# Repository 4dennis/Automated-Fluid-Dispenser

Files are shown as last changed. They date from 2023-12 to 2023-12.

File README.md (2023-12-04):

# Automated-Fluid-Dispenser
Automated Fluid Dispenser code for a rotating rack that holds 5 test tubes and dispenses software-specified amounts of powder and liquid without user input. Includes emergency stop button. Uses an Arduino, limit switch, 2x push buttons, fluid pump, continuous servo, and a DC motor\
**For Solidworks files:** \
  Use Goat.forEdit4 assembly file\
  NoPrint indicates a part that is not for 3D or acrylic but is included in the build\
  AC indicates acrylic\
  3D indicates 3D printing\
  Nx where x stands for the number of pieces to produce\
\
-project created for APSC 101 with team members: Simon W., Lydia H., Cady K., Brady B.

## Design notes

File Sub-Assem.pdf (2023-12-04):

Automated Fluid Dispenser

29/10/23

| i

## Table of Contents

## 1. Exploded Views

Below is an exploded view of the entire assembly and each subassembly

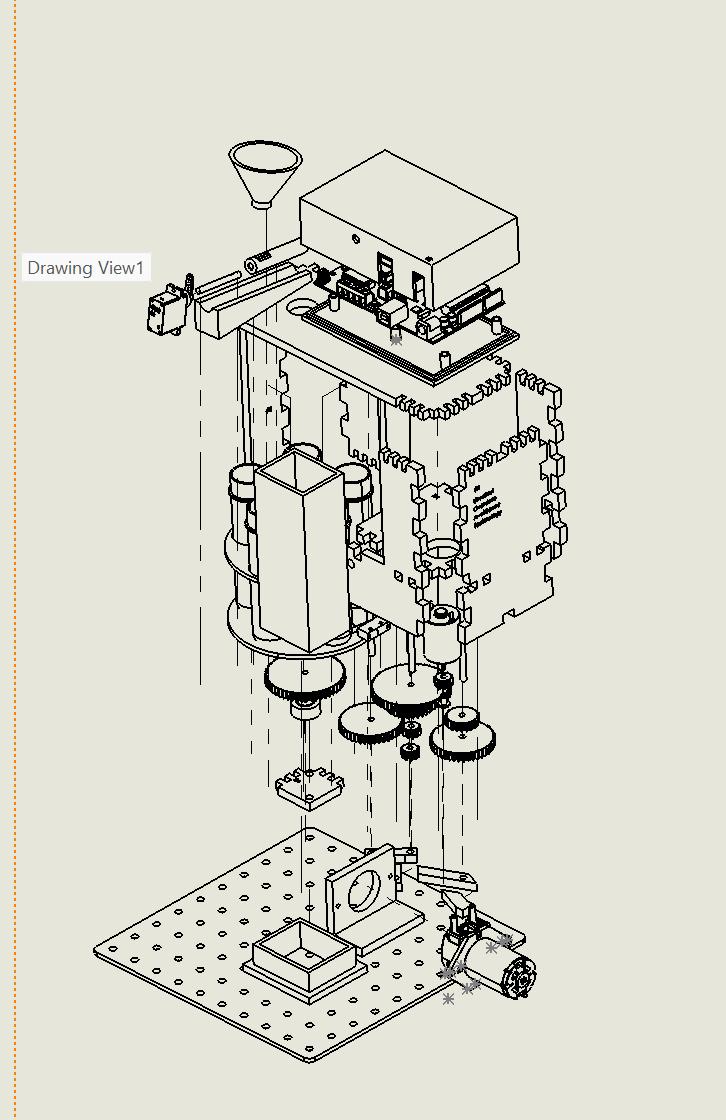
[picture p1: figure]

1.1 Exploded View of the Entire Assembly

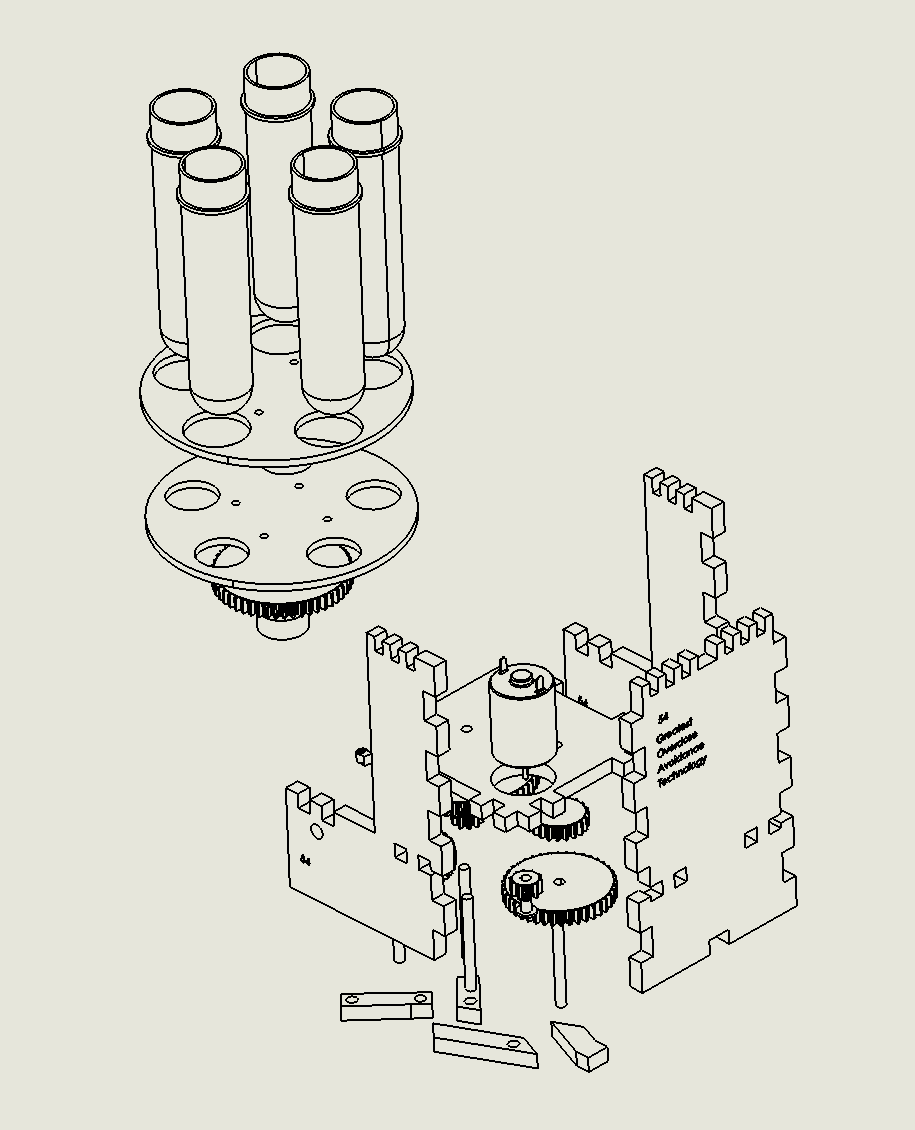
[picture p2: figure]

1.2 Exploded View of Gearbox and Turntable

### 1.3 Exploded View of Mast and Top of the Mast

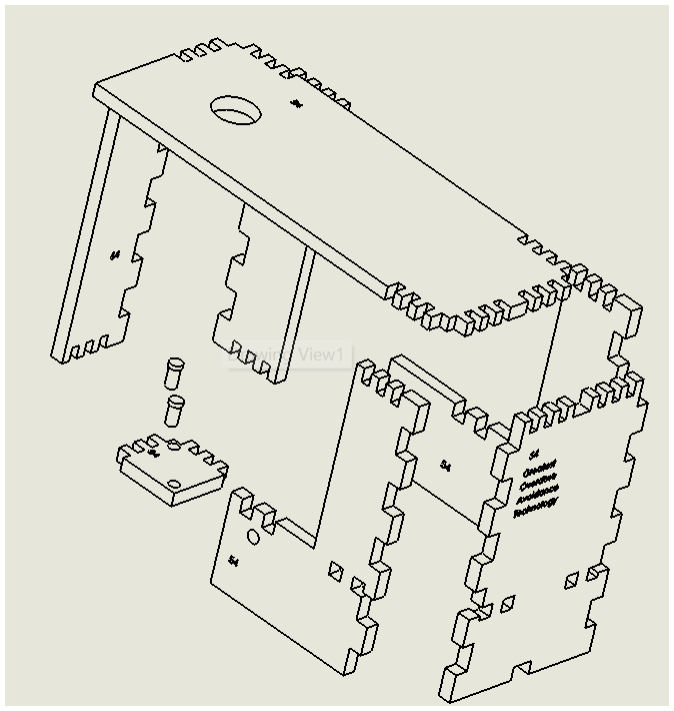
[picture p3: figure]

### 1.4 Exploded View of Powder Dispensary

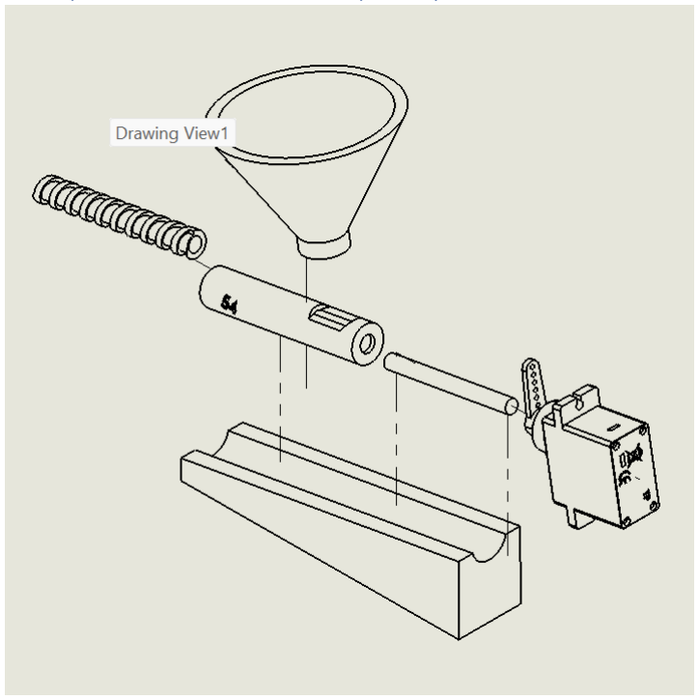
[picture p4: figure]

### 1.5 Exploded View of Liquid Dispensary

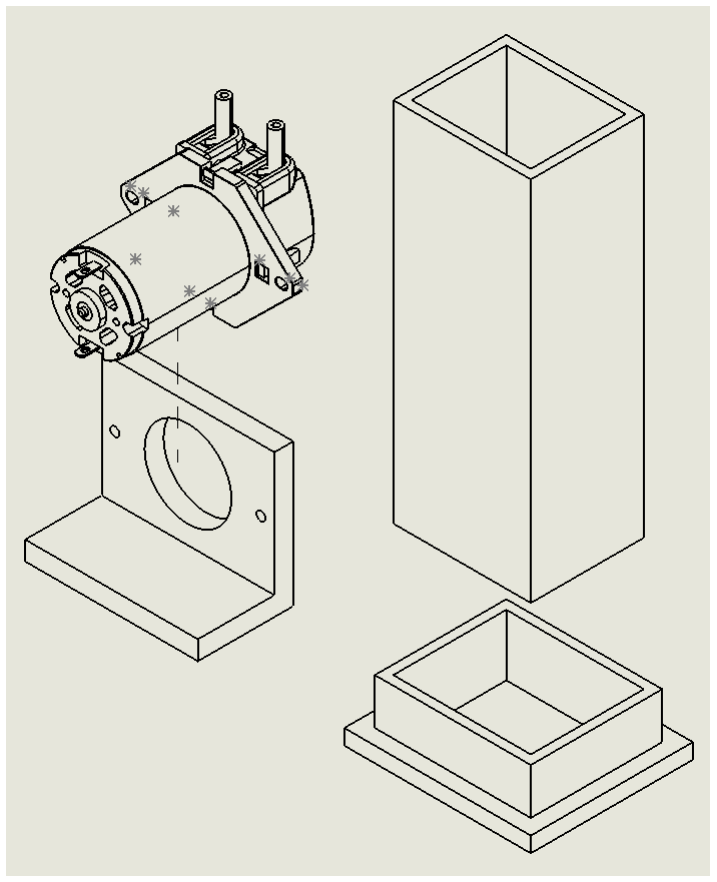
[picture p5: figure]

## 2. Bill of Materials

Below is a bill of material generated form SolidWorks with all items and the quantity of each one.

ITEM
NO. | PART NUMBER | DESCRIPTION QTY.
1 | 054_10T_NOPRINT_N3 | 10 Tooth
| | Gear | 3
2 | 054_20T_NOPRINT_N1 | 20 Tooth
| | gear | 1
3 | 054_40T_NOPRINT_N2 | 40 tooth
| | gear | 2
4 | 054_50T_NOPRINT_N2 | 50 tooth
| | gear | 2
5 | 054_30T_NOPRINT_N1 | 30 tooth
| | gear | 1
6 | DCMotor1 | DC motor | 1

7

054_Bushing_NOPRINT_
| n1 | bushing

1

8 | 054_Shaft_NOPRINT_N4 | gearbox
| | shaft

5

9 | 054_GearboxBack_AC
| _N1 | gearbox
| | back

1

10 | 054_Pegboard_NOPRI
| NT_N1 | pegboard

1

11 | 054_mastwall_AC_N2 | wall of mast

2
12 | 054_topofmast_AC_N1 | top of mast

1
13 | 054_bracket_AC_N1 | bracket for
| | mast

1

14 | 054_Peg_NOPRINT_N2 | peg for mast

2
15 | 054_GearboxSide2_AC
| _N1 | gearbox
| | side 2

1

16 | 054_GearBoxRoof_AC_
| N1 | gearbox
| | roof

1

17 | 054_Rack_NOPRINT_N1 | test tube
| | rack

1

18 | 054_TestTube_NOPRINT
| _N5 | test tube

5

19 | 054_PumpHolder_NOP
| RINT_N1 | holder for
| | pump

1

20 | 054_Pump_NOPRINT_N 1 | pump
1
21 | 054_Reservoir_NOPRINT
| _N1 | reservoir

1

22 | 054_ResevoireHolder_
| NOPRINT_N1 | reservoir
| | holder

1

23 | 054_LimitSwitch_NOPRI
| NT_N1 | limit switch

1

24 | 054_GearboxSide1_AC
| _N1 | gearbox
| | side 1

1

25 | 054_GearboxBottom1_
| AC_N1 | gearbox
| | bottom
| | segment 1

1

26 054_GearboxBottom2_ AC_N1

gearbox
bottom
segment 2

1

27 054_GearboxBottom3_ AC_N1

gearbox
bottom
segment 3

1

28 054_GearboxBottom4_ AC_N1

gearbox
bottom
segment 4

1

29 054_ArduinoHousingBo
ttom_NOPRINT_N1

arduino
housing
bottom

1

30 | 054_ArduinoUno_NOPR
INT_N1 | arduino uno

1

31 | 054_Motorshield_NOPR
INT_N1 | motorshield

1

32 054_ArduinoHousingTo
p_NOPRINT_N1

arduino
housing top

1

33 054_BearingInnerRing_
NOPRINT_N1

bearing
inner ring

1

34 054_BearingOuterRing_
NOPRINT_N1

bearing
outer ring

1

35 | 054_Bearing_NOPRINT_
N5 | bearing ball

5

36 | 054_NewPowderFunne
l_3D_N1 | funnel

1

37 | 054_PowderWormDrive
_3D_N1 | worm gear

1

38 054_PowderHousing_3
D_N1

powder
housing

1

39 054_PowderStand_NO
PRINT_N1

stand for
housing

1

40 | Servo_SG90
- Updated | servo motor

1

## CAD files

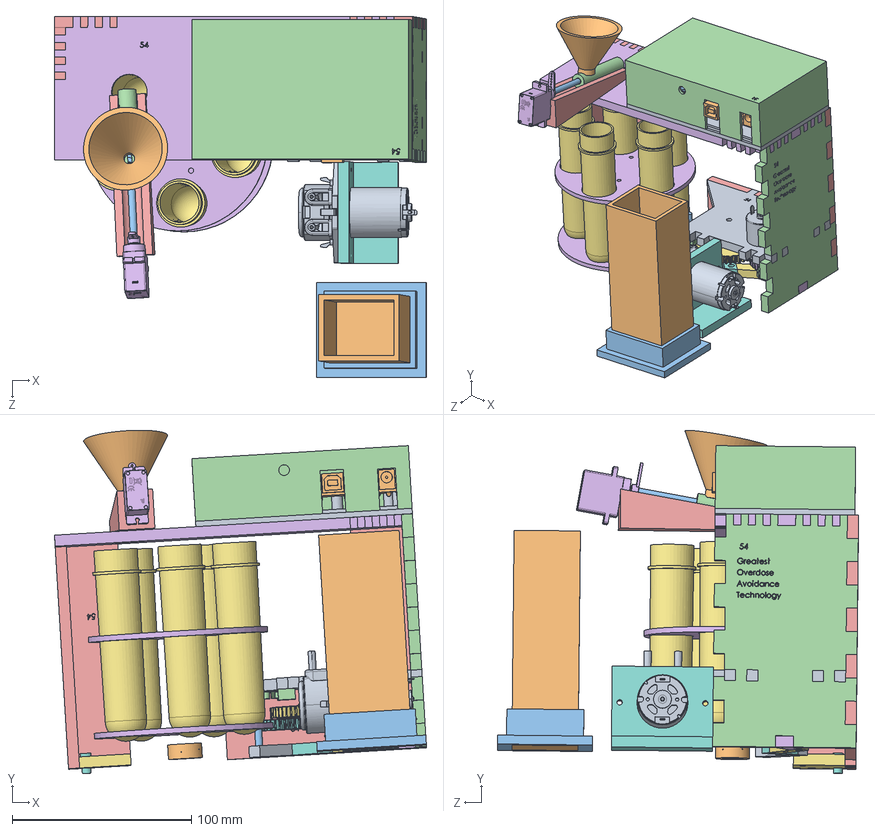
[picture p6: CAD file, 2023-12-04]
AFD_SOLIDWORKS/Goat.forEdit4.SLDASM
207.5 x 191.5 x 201.4 mm
054_mastwall_AC_N2 x 2
054_topofmast_AC_N1
054_bracket_AC_N1
054_ArduinoHousingBottom_NOPRINT_N1
054_ArduinoUno_NOPRINT_N1
054_Motorshield_NOPRINT_N1
054_ArduinoHousingTop_NOPRINT_N1
054_BearingInnerRing_NOPRINT_N1
054_BearingOuterRing_NOPRINT_N1
054_Bearing_NOPRINT_N5 x 5
054_GearBoxRoof_AC_N1
054_Rack_NOPRINT_N1
054_TestTube_NOPRINT_N5 x 5
054_PumpHolder_NOPRINT_N1
054_Pump_NOPRINT_N1
054_Reservoir_NOPRINT_N1
054_ResevoireHolder_NOPRINT_N1
054_LimitSwitch_NOPRINT_N1
054_GearboxSide1_AC_N1
054_GearboxBottom1_AC_N1
054_GearboxBottom2_AC_N1
054_GearboxBottom3_AC_N1
054_GearboxBottom4_AC_N1
054_NewPowderFunnel_3D_N1
054_PowderWormDrive_3D_N1
054_PowderHousing_3D_N1
054_PowderStand_NOPRINT_N1
054_Shaft_NOPRINT_N4
Servo_SG90 - Updated

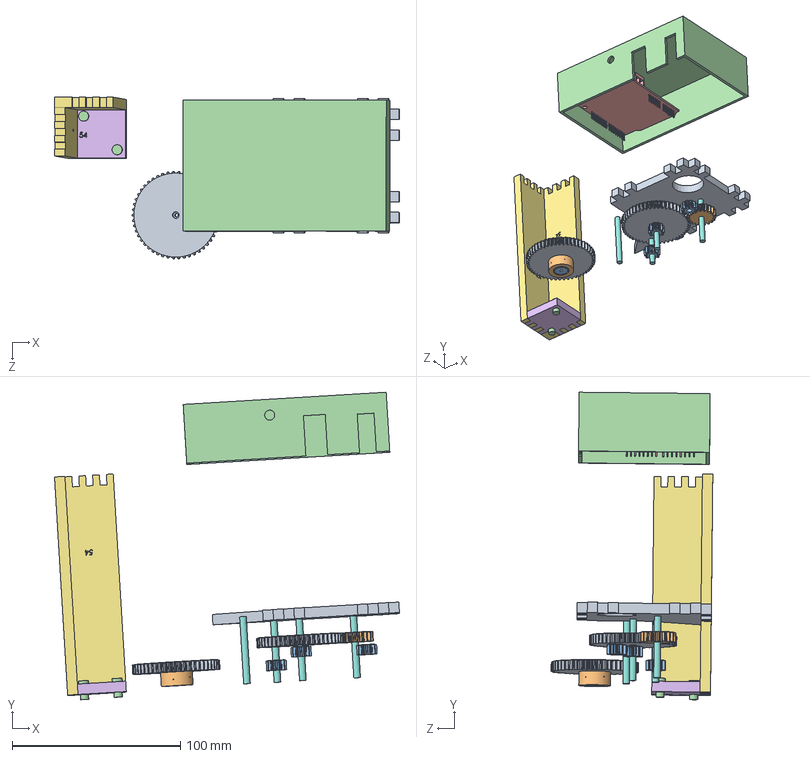
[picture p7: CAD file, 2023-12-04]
AFD_SOLIDWORKS/Goat.forEdit3.SLDASM
205.2 x 183.0 x 96.2 mm
054_10T_NOPRINT_N3 x 3
054_20T_NOPRINT_N1
054_50T_NOPRINT_N2 x 2
054_Shaft_NOPRINT_N4 x 4
054_mastwall_AC_N2 x 2
054_bracket_AC_N1
054_Peg_NOPRINT_N2 x 2
054_Motorshield_NOPRINT_N1
054_ArduinoHousingTop_NOPRINT_N1
054_BearingInnerRing_NOPRINT_N1
054_BearingOuterRing_NOPRINT_N1
054_Bearing_NOPRINT_N5 x 5
054_GearBoxRoof_AC_N1

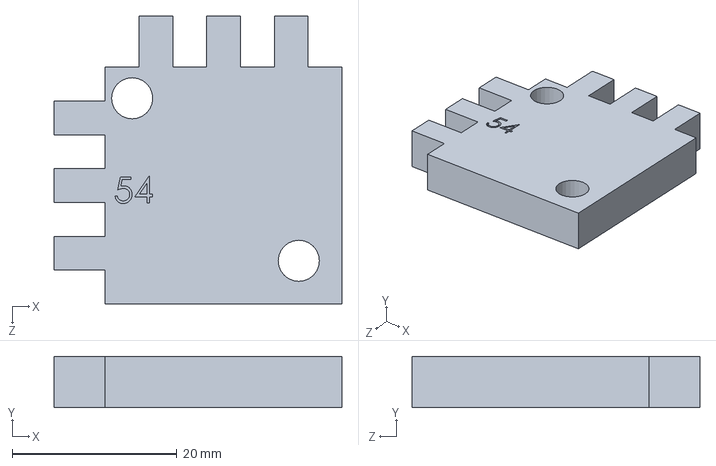
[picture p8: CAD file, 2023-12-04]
AFD_SOLIDWORKS/054_bracket_AC_N1.SLDPRT
35.0 x 6.20 x 35.0 mm

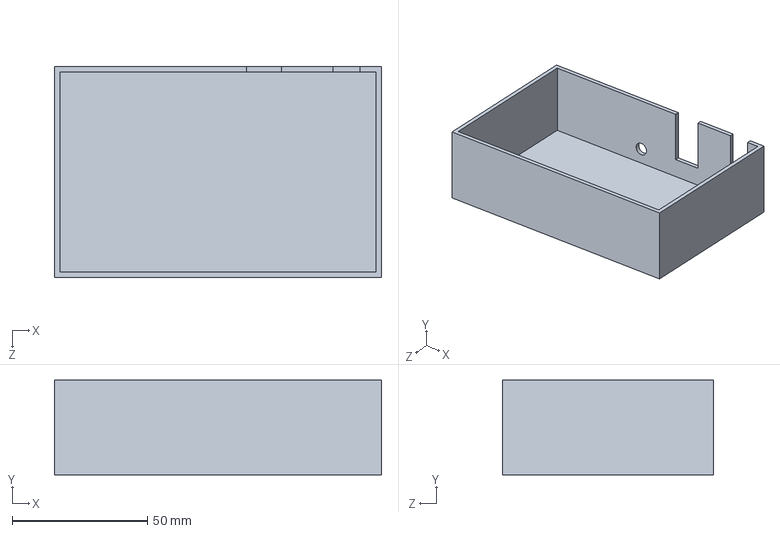
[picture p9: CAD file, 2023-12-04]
AFD_SOLIDWORKS/054_ArduinoHousingTop_NOPRINT_N1.SLDPRT
121.0 x 35.0 x 78.0 mm

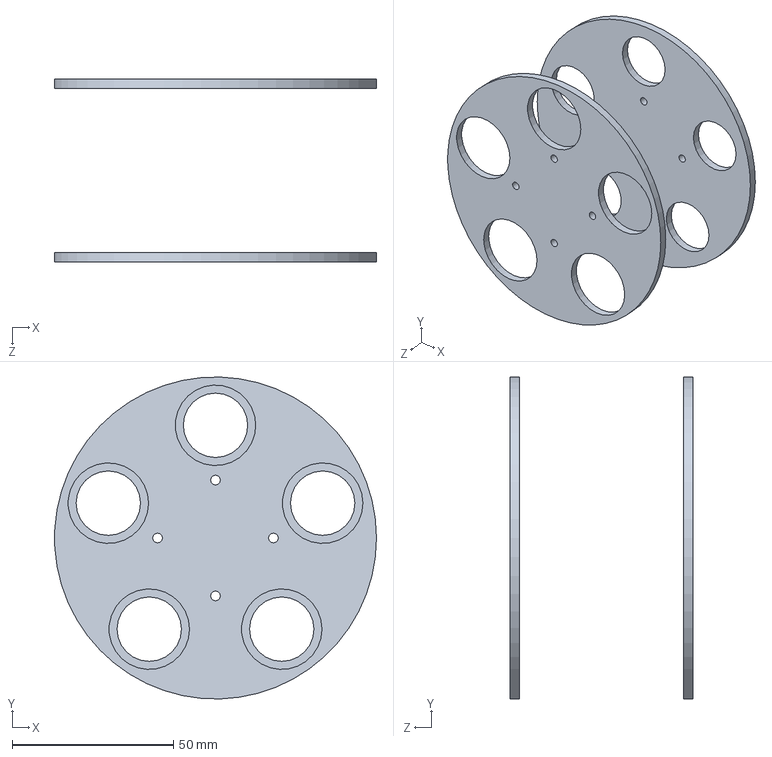
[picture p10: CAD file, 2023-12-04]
AFD_SOLIDWORKS/054_Rack_NOPRINT_N1.SLDPRT
100.0 x 100.0 x 56.8 mm

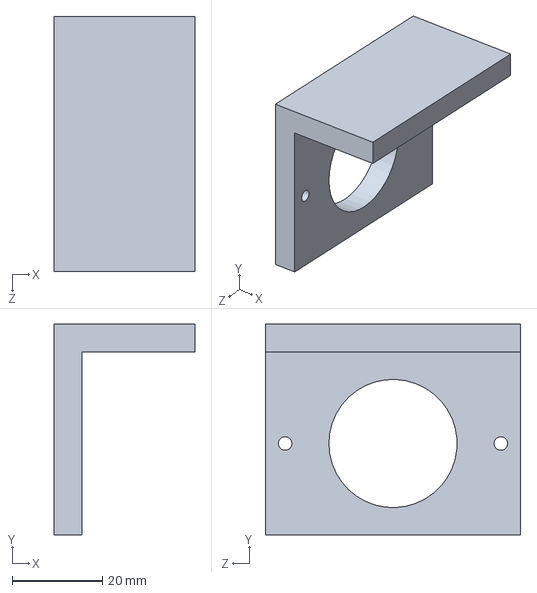
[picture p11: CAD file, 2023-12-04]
AFD_SOLIDWORKS/054_PumpHolder_NOPRINT_N1.SLDPRT
31.2 x 46.7 x 56.5 mm

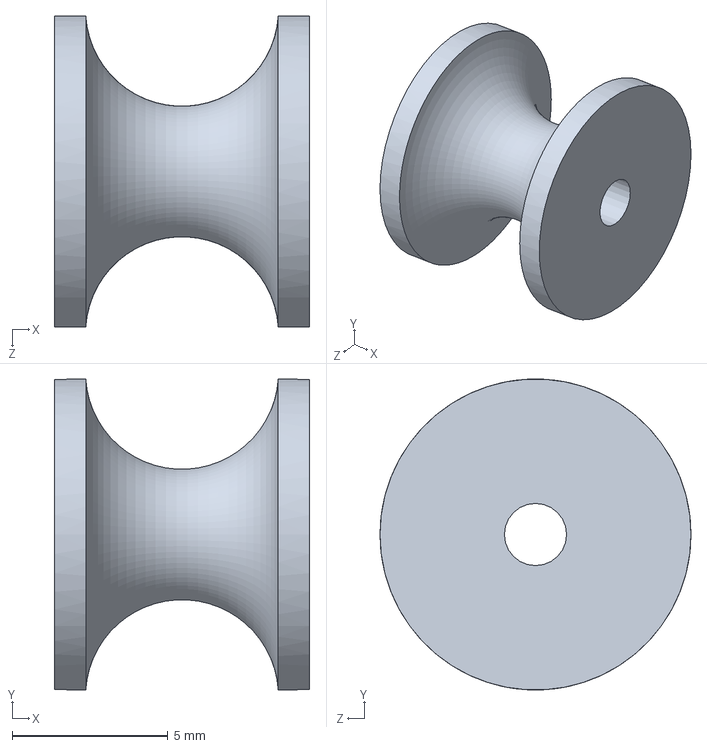
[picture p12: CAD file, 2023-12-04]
AFD_SOLIDWORKS/054_BearingInnerRing_NOPRINT_N1.SLDPRT
8.20 x 9.99 x 10.0 mm

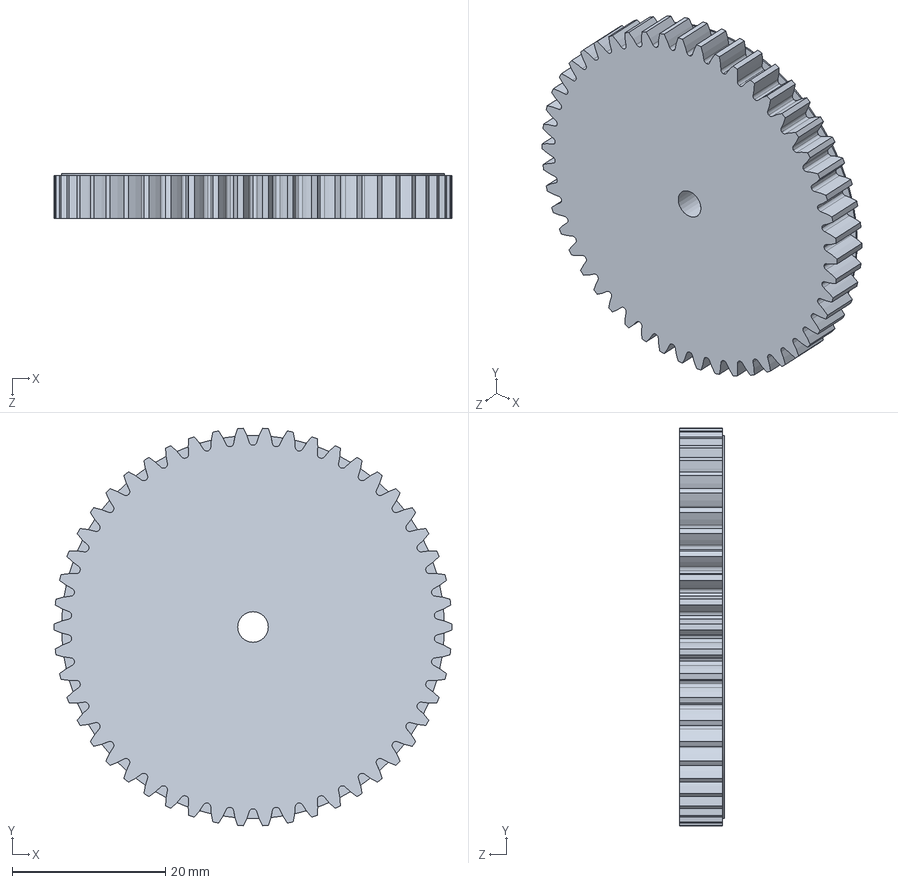
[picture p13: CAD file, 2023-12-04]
AFD_SOLIDWORKS/054_50T_NOPRINT_N2.SLDPRT
52.0 x 51.9 x 5.85 mm

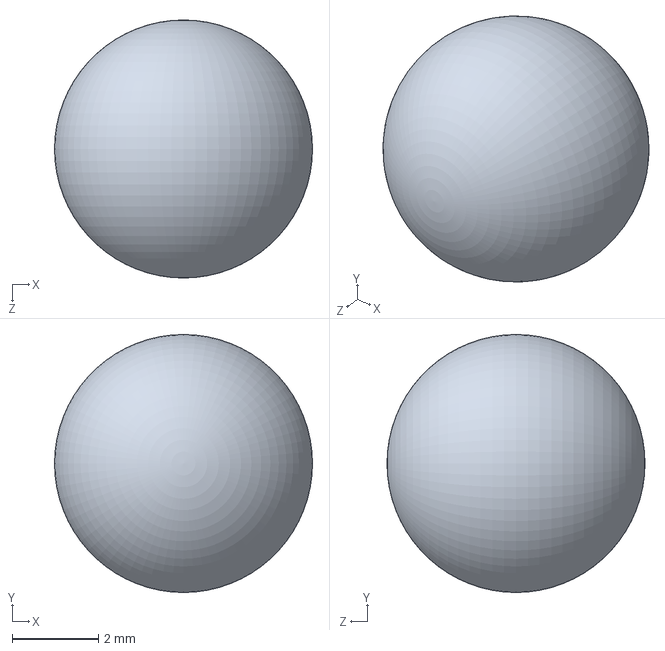
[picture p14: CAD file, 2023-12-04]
AFD_SOLIDWORKS/054_Bearing_NOPRINT_N5.SLDPRT
6.00 x 6.00 x 6.00 mm

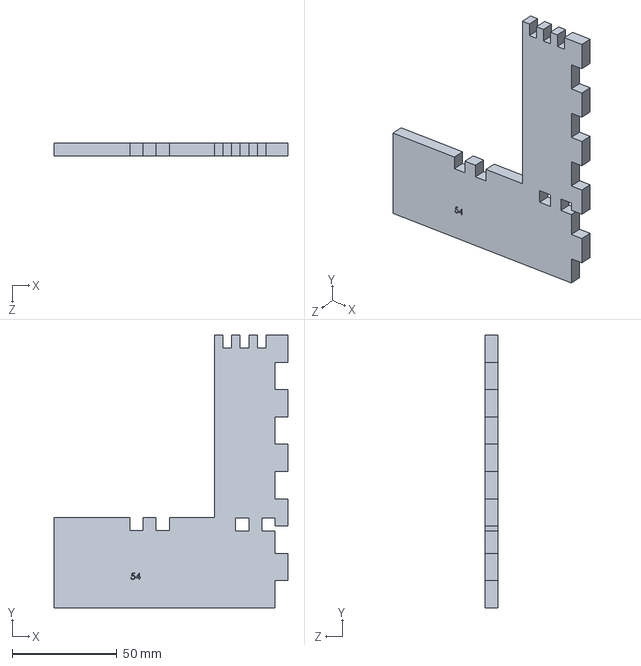
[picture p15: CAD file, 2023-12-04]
AFD_SOLIDWORKS/054_GearboxSide1_AC_N1.SLDPRT
111.3 x 130.0 x 6.20 mm

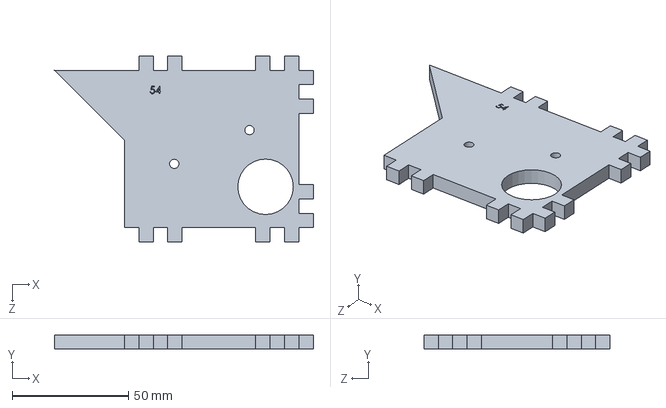
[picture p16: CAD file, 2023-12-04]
AFD_SOLIDWORKS/054_GearBoxRoof_AC_N1.SLDPRT
111.2 x 6.20 x 80.0 mm

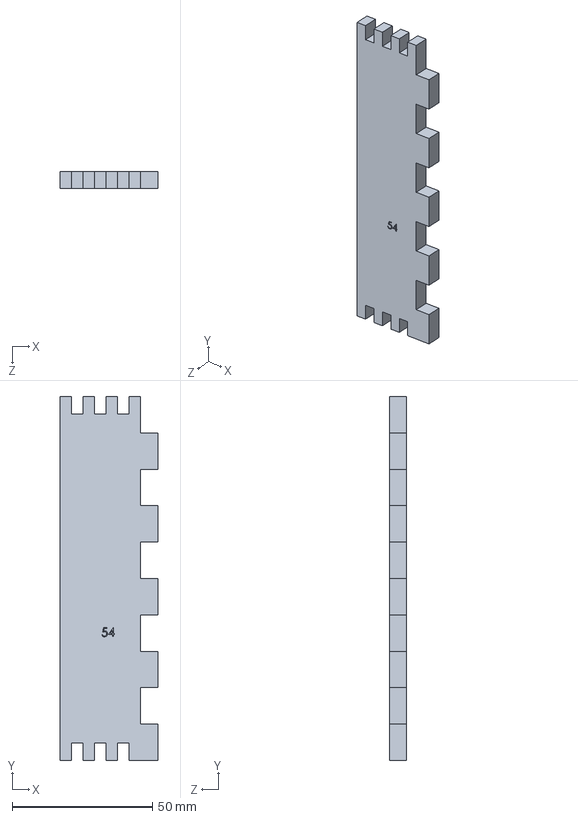
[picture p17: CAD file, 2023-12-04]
AFD_SOLIDWORKS/054_mastwall_AC_N2.SLDPRT
35.0 x 130.0 x 6.20 mm

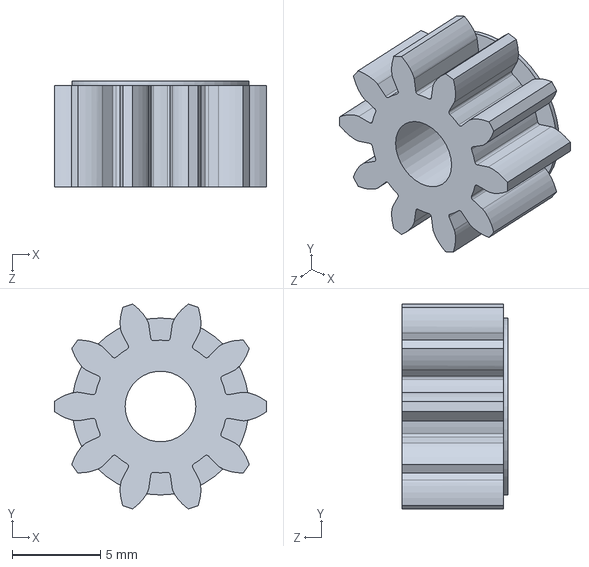
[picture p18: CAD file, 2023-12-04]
AFD_SOLIDWORKS/054_10T_NOPRINT_N3.SLDPRT
12.0 x 11.6 x 6.00 mm

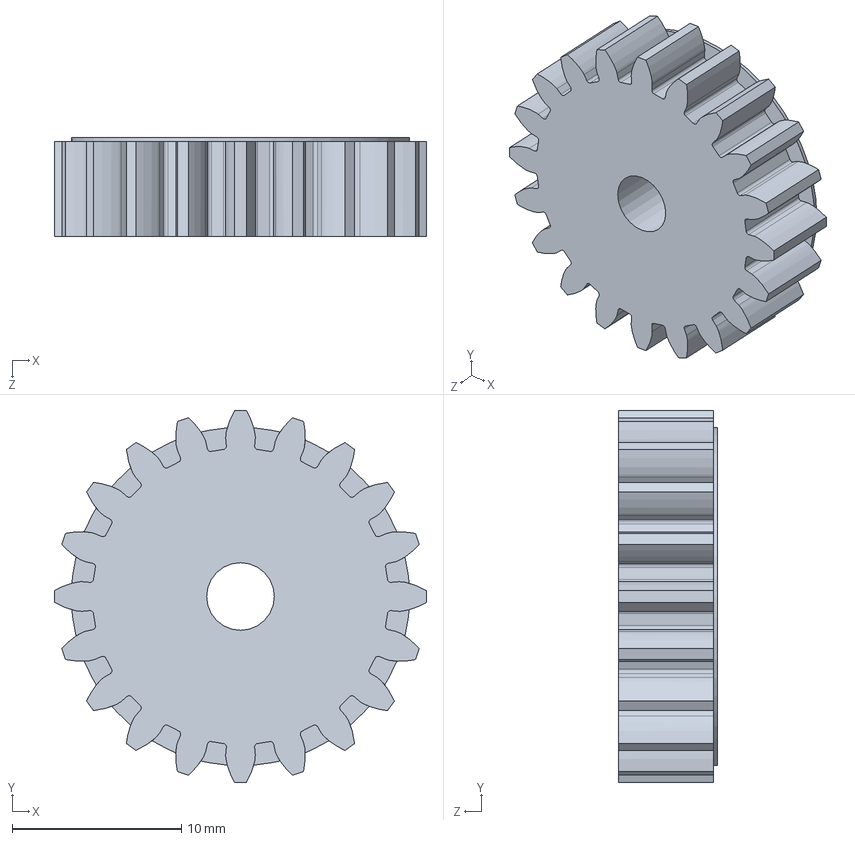
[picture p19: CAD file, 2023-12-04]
AFD_SOLIDWORKS/054_20T_NOPRINT_N1.SLDPRT
22.0 x 22.0 x 5.85 mm

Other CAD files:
AFD_SOLIDWORKS/054_BearingOuterRing_NOPRINT_N1.SLDPRT
AFD_SOLIDWORKS/054_Motorshield_NOPRINT_N1.SLDPRT
AFD_SOLIDWORKS/054_Pump_NOPRINT_N1.SLDPRT
AFD_SOLIDWORKS/054_Shaft_NOPRINT_N4.SLDPRT
AFD_SOLIDWORKS/054_30T_NOPRINT_N1.SLDPRT
AFD_SOLIDWORKS/054_40T_NOPRINT_N2.SLDPRT
AFD_SOLIDWORKS/054_ArduinoHousingBottom_NOPRINT_N1.SLDPRT
AFD_SOLIDWORKS/054_ArduinoUno_NOPRINT_N1.SLDPRT
AFD_SOLIDWORKS/054_Bushing_NOPRINT_n1.SLDPRT
AFD_SOLIDWORKS/054_GearboxBack_AC_N1.SLDPRT
AFD_SOLIDWORKS/054_GearboxBottom1_AC_N1.SLDPRT
AFD_SOLIDWORKS/054_GearboxBottom2_AC_N1.SLDPRT
AFD_SOLIDWORKS/054_GearboxBottom3_AC_N1.SLDPRT
AFD_SOLIDWORKS/054_GearboxBottom4_AC_N1.SLDPRT
AFD_SOLIDWORKS/054_GearboxSide2_AC_N1.SLDPRT
AFD_SOLIDWORKS/054_LimitSwitch_NOPRINT_N1.SLDPRT
AFD_SOLIDWORKS/054_NewPowderFunnel_3D_N1.SLDPRT
AFD_SOLIDWORKS/054_Peg_NOPRINT_N2.SLDPRT
AFD_SOLIDWORKS/054_Pegboard_NOPRINT_N1.SLDPRT
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

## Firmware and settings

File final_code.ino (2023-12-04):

//Fully functional code for group 54's AFD


//add libraries
#include <AFMotor.h>
#include <Servo.h>

//setup buttons
#define pbStart A1
#define pbStop A2
#define limitSwitch A3

//set button states
bool pbStartState = HIGH;
bool pbStopState = HIGH;
bool limitSwitchState = HIGH;
bool startProgram = false;



//define DCmotor and base speed
AF_DCMotor DCmotor(1);
const int DCSpeed = 110;

//setup servo - we are using a continious servo FS90
#define myServo_PIN_SIG	2
Servo myServo;
int STOP = 93; //stop speed for continious servo

//setup water pump
AF_DCMotor pump(4);


//declare array to hold the amount of time to dispense
const unsigned long ST[5] = {18000, 18000, 36000, 18000, 18000};             //servo time 18000ms/g         mass (g) * rate = ms  //final task 1g, 1g, 2g, 1g, 1g
const unsigned long WT[5] = {21367, 21367, 21367, 21367, 21367};            //water time 0.000936ml/ms     vol (ml) / rate = ms  //20mL in each

int count = 0; //for each test tube count
int lengthDelay = 10; //universal delay length


//---------------
//Functions

//Timing Code
//servo run for this amount of time
void servoTime(long x){
  Serial.print("servoTime\n");

  for(long i=0; i < x; i += lengthDelay){
    pbStopState = digitalRead(pbStop); //get button state each time

    if(pbStopState == LOW){ //emergency switch check
      emergencyStop();
    }
    else{
    myServo.write(110); // run servo
    delay(lengthDelay);
    }
  }
  myServo.write(STOP); //stop when time done
}

//DCMotor run for this amount of time
void dcTime(long x){
  Serial.print("dcTime\n");
  DCmotor.run(FORWARD); //start with motor run


  for(long i=0; i < x; i += lengthDelay){
  pbStopState = digitalRead(pbStop); //check button states
  limitSwitchState = digitalRead(limitSwitch);


    if(pbStopState == LOW){
      emergencyStop();
    }
    else if(limitSwitchState == LOW){ //once testube hit limit switch stop motor, exit loop
      DCmotor.run(RELEASE);
      Serial.print("dcStop\n");

      return;
    }
    else{
    Serial.print("dcRun\n");

    DCmotor.run(FORWARD);
    
    }
  }
  DCmotor.run(RELEASE);
}

//Water Pump run for this amount of time
void pumpTime(long x){
  //run pump for given time unless emergency stopped
  Serial.print("pumpTime\n");

  for(long i=0; i < x; i += lengthDelay){
    pbStopState = digitalRead(pbStop);

    if(pbStopState == LOW){
      emergencyStop();
    }
    else{
    pump.setSpeed(255);
    pump.run(FORWARD);
    delay(lengthDelay);
    }
  }
  pump.run(RELEASE);
}


//Emergency Stop code
void emergencyStop(){
  while(1<2){
    if (pbStopState==LOW){
      DCmotor.run(RELEASE); //stop DC
      myServo.write(STOP); //stop servo
      pump.run(RELEASE);  //stop water pump
      Serial.print("emergency stop hit\n");  
      
    }  
    
    for(;;){ //endless loop to stop
      DCmotor.run(RELEASE); //stop DC
      myServo.write(STOP); //stop servo
      pump.run(RELEASE);  //stop water pump
    } 
    return;
  }
}

// 

void setup() {
  // Start serial monitor
    Serial.begin(9600);

  pinMode(pbStart, INPUT_PULLUP);
  pinMode(pbStop, INPUT_PULLUP);
  pinMode(limitSwitch, INPUT_PULLUP);
  myServo.attach(9); // attach the servo
  myServo.write(STOP); //stop servo
  DCmotor.setSpeed(DCSpeed);
  DCmotor.run(RELEASE); // stop DC motor
  pump.run(RELEASE); //stop water pump

  Serial.print("completed setup\n");


}

void loop() {

  //Serial.print("looping\n");
  //get button states
  pbStartState = digitalRead(pbStart);
  pbStopState = digitalRead(pbStop);
  limitSwitchState = digitalRead(limitSwitch);


 if(pbStopState==LOW){
    emergencyStop();
 }
 else if(pbStartState == LOW){
    startProgram = true; // set flag to be able to start program
    Serial.print("Starting program\n");
    delay(1000); //delay program from start button
 }
 else if (count < 5 && startProgram == true){
    Serial.print(count);
    Serial.print("running\n");
    

    dcTime(15000); //run the motor, it goes off limit switch to stop but otherwise will stop in default 15seconds 
    delay(500); //small delay between actions
    servoTime(ST[count]); //servo code based on array position for test tube position 
    delay(500);
    pumpTime(WT[count]);
    delay(500);

    count++; //increse test tube count
 }
}

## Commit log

2023-12-04 Arduino code
2023-12-04 solidworks files
    use Goat.forEdit4 assembly file
    NoPrint indicates a part that is not for 3D or acrylic but is included in the build
    AC indicates acrylic
    3D indicates 3D printing
    Nx where x stands for number of pieces to produce
    [054_10T_NOPRINT_N3.SLDPRT, 054_20T_NOPRINT_N1.SLDPRT, 054_30T_NOPRINT_N1.SLDPRT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]
2023-12-04 sub assembly drawings with bill of material
